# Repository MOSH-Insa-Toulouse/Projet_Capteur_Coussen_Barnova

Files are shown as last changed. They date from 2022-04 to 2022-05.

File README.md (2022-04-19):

# Projet_Capteur_Coussen_Barnova
 2021-2022
 Low-tech pencil drawn strain gauge sensor developed in 4th year Engineering Physics course MOSH (Microcontroller Open Source Hardware) at INSA (National Institute of Applied Sciences) Toulouse.

The project is inspired by Scientific Reports article "Pencil Drawn Strain Gauges and Chemiresistors on Paper" written by Cheng-Wei Lin, Zhibo Zhao, Jaemyung Kim & Jiaxing Huang. This article can be found in our repository.

The aim of this project is to fabricate a reliable strain gauge made of pencil drawn paper.

## Idea
Pencil carbon deposited on the paper is made of percolated graphite particles network where electrons move. Mechanism enabling electrons to move from grain to grain is tunnelling through potential barrier. However, tunnelling depends exponentially on the length of the barrier. When a mechanical stress is applied to the gauge, grains of percolated network spread away. Thus, when a tension is applied to gauge electrons move less => resistance increases. When gauge is compressed electrons move more => resistance decreases.

## Hardware implementation
A photo of our sensor can be found in the repository.

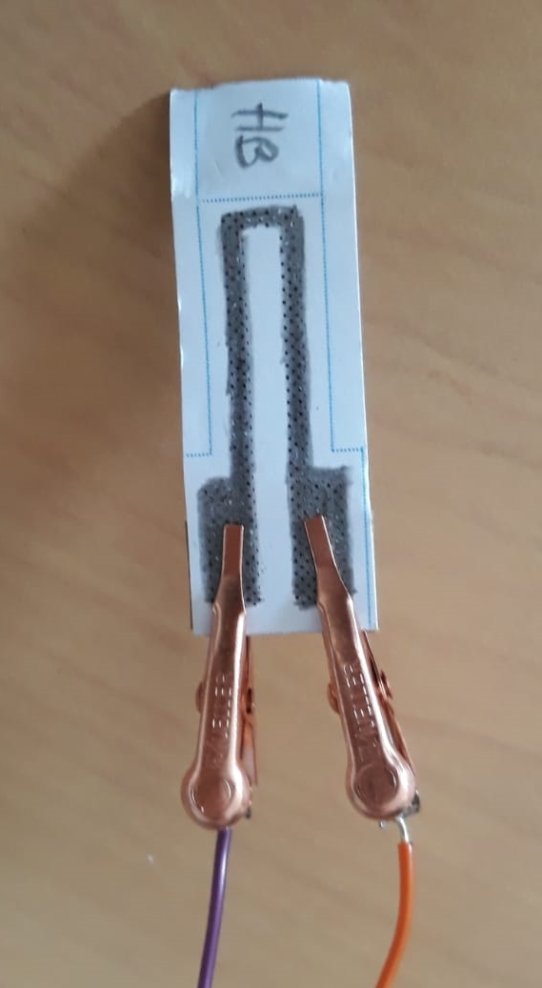
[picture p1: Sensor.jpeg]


Supplying the sensor with 5V induces current in the sensor. However, this current has an order of magnitude of a nanoampere. Ordinary multimeter is not able to detect such a small current. We use LTC1050 amplifier which enables to convert current into a voltage that can be measured thanks to Arduino Uno board.
We dimensioned amplifier circuit in order to filter 50 Hz noise and cut off high frequencies. Further explanations are contained in Electronic_simulation_LTSpice document.
We designed this electrical circuit as a shield PCB (printed circuit board) using KiCad 6.0 software and printed it. KiCad files can be found in KiCad directory.

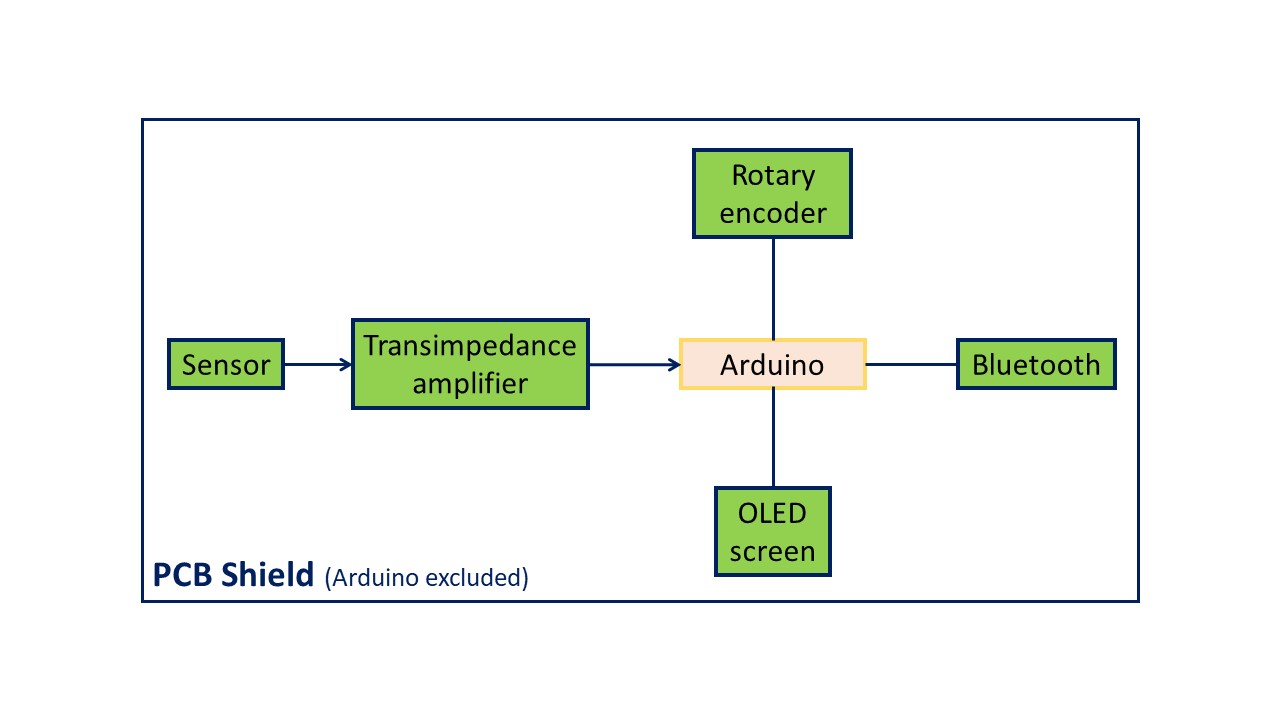
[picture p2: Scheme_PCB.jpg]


## Software implementation
With a focus on customized Arduino board we've written Arduino programs to run OLED screen, rotatory encoder and HC-O5 Bluetooth module enabling to send mesasured data to a smartphone. This code can be found in the directory "code_Arduino". To run the code you will need to download Adafruit_1306 library.
We developed this code without PCB and for the sake of simplicity and efficiency we changed one pin between PCB and code. Switch pin of the rotary encoder is wired to the pin 3 of Arduino instead of pin 5 (as in PCB). The reason is that we use Interrupts in the code and they can be generated only by the Arduino pins 2 and 3.  
Finally, we designed a simple app on MIT App Inventor that receives and plots the data. It can be found in the directory "App". Our app fails when it receives inf value and we did not eliminate this bug. 

## Tests and results

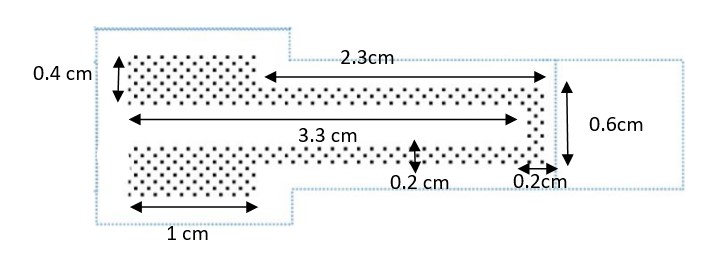
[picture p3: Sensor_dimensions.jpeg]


Our sensor can be drawn with different pencils. Their content is a mixture of clay and carbon. Pencils containing more clay are indicated with H meaning "high". Their stroke is light. Pencils containing more carbon are indicated with B meaning "low" and they draw bolder lines. Here is scale of pencils hardness.



Results can be found in the file Measures. We get linear slope of the calibration curve which confirms that resistance depends on strain. It is possible to make a sensor with pencil drawn paper. We note that sensibility of our sensor is the slope of the linear function - for HB it is 14 385 Mohms/m.
Even though, our sensor gives limited results, we measured how the resistance changes as a function of curvature and we are able to link it to bending. This explanation can be found in the document "Test bench". However, wires connection induced on paper a lot of error because of lack of stability.

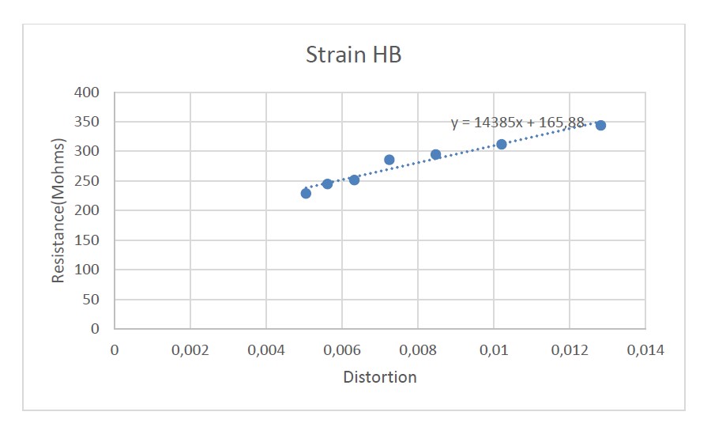
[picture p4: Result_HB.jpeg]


## Limits 
Firstly, PCB oxydized which lead to its malfunction. Most probably, certain pins were connected with the pins they were not supposed to which hindered correct supply and transit.
Furthermore, resistance depends clearly on amount of carbon deposited. This factor is quite difficult to evaluate and to control in our conditions.
Moreover, our measures are not repeatable because paper distorts when we measure relatively big strain. 
Finally, wire connections slip on the paper which alters the resistance. We would need a more reliable connection to decrease average error and get more repeatable results. We could possibly imagine a solution to stabilize the position of the wires connections relatively to each other. 

## Authors
Sarah Barnová : barnova@insa-toulouse.fr
Louise Coussen : coussen@insa-toulouse.fr

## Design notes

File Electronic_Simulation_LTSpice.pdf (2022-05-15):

## Partie électronique analogique - Simulation électrique sous LTSpice

### Sarah Barnova – Louise Coussen

Afin de mesurer la résistance d’un capteur de graphite, on utilise un amplificateur de transimpédance. En effet, on dépose du graphite en frottant un crayon à papier contre un morceau de papier qui fera office de résistance à mesurer. En alimentant le circuit en tension à 5V, on peut considérer ce générateur de tension en série avec notre résistance, que l’on nommera Rsensor. On modélise alors cette configuration par un générateur de courant que l’on nomme Isens. Ainsi, on impose I grâce à une tension d’alimentation fixe et la résistance inconnue Rsensor, et on cherche à mesurer VADC pour déduire cette valeur inconnue. On utilise donc un amplificateur de transimpédance, qui convertit courant en tension.

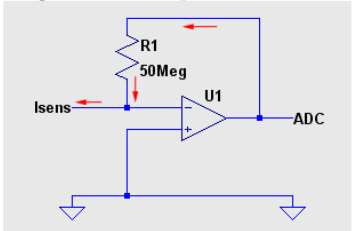
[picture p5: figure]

Le schéma ci-dessus présente la solution la plus minimaliste possible, toutefois, il présente quelques défauts : en effet, le capteur doit être alimenté par une tension négative, et R1 doit être très importante. Toutefois, afin de garantir le bon fonctionnement de ce montage, il est nécessaire d’y implémenter 3 filtres dont nous allons étudier successivement le rôle. Voici donc un amplificateur de transimpédance à 2 étages :

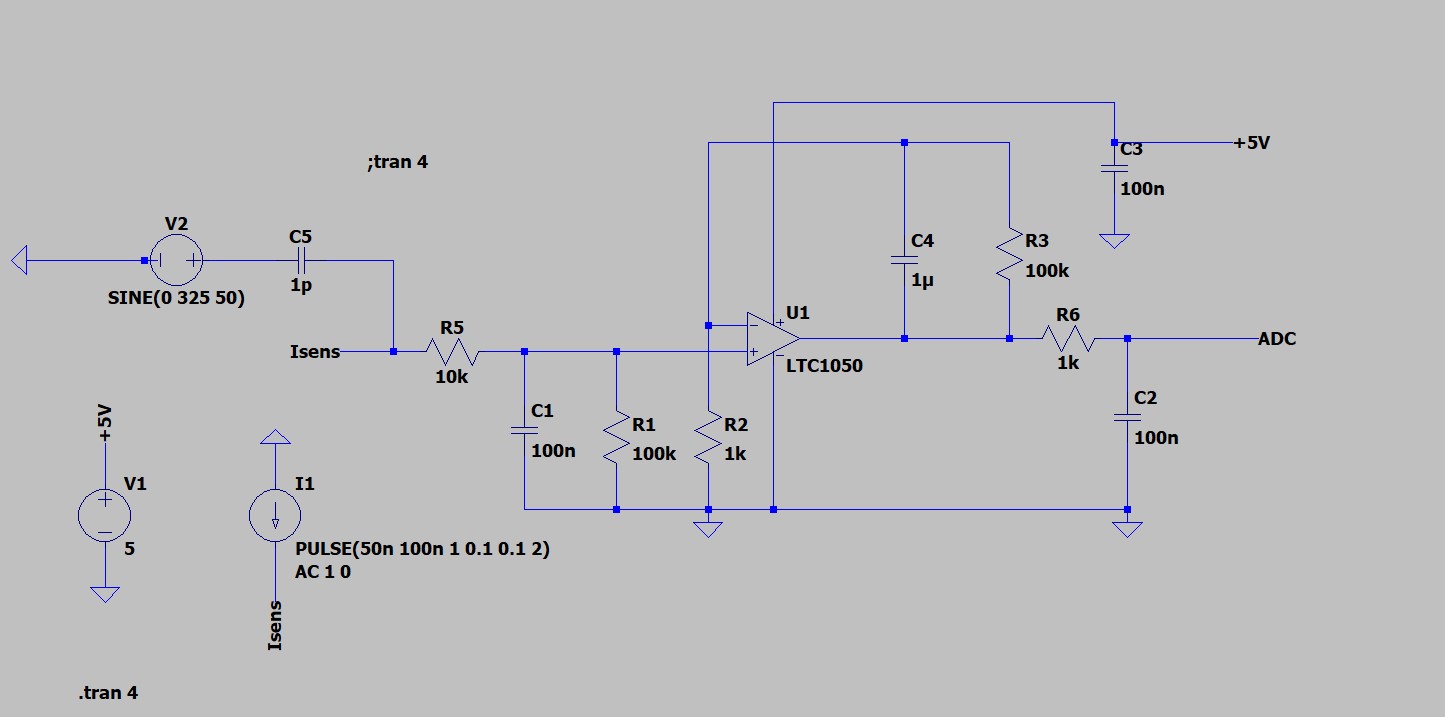
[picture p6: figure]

## Filtre 1 : R1 – C1, filtre passe-bas contre le bruit en courant

Ce premier filtre passe-bas est un filtre RC permettant d’éviter des oscillations trop élevées sur le signal capteur.

On calcule sa fréquence de coupure théorique : f =

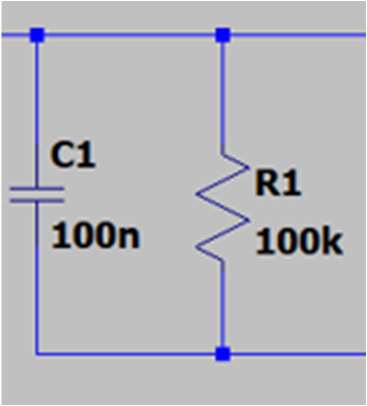
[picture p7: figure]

×.×.

= 15,9 Hz

On simule retrouve cette fréquence de coupure sous LTSpice en désactivant les capacités des autres filtres (on leur confère 0 pour valeur).

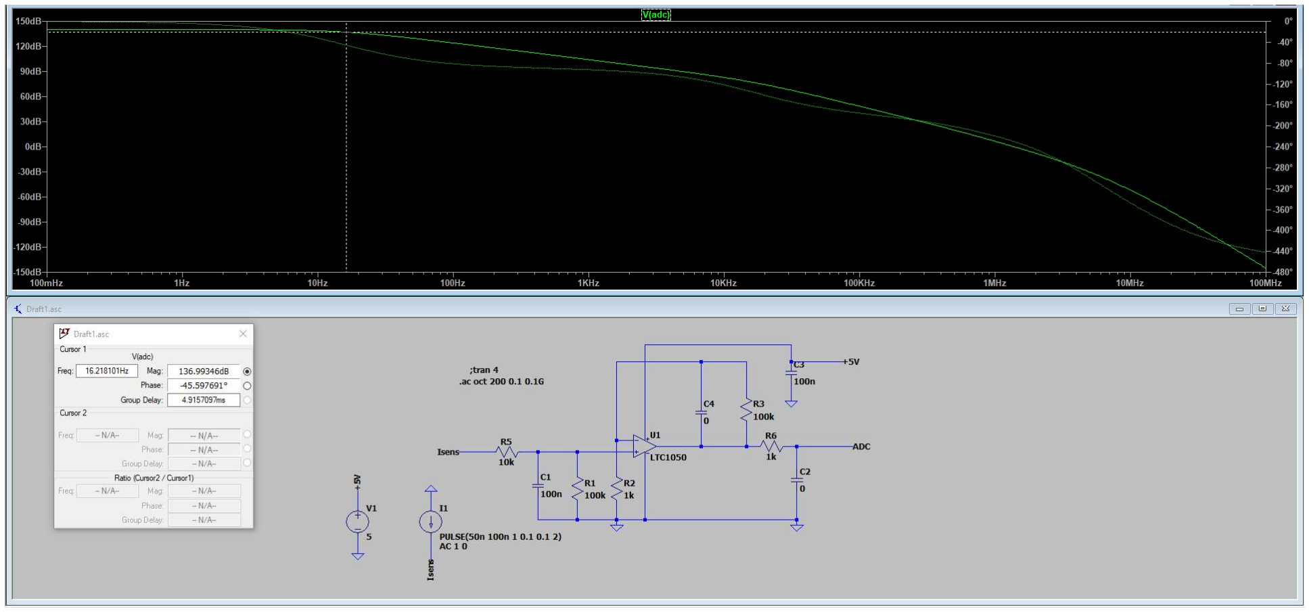
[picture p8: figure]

## Filtre 2 : R3 – C4, filtre actif contre le bruit à 50 Hz

Ce second filtre passe-bas permet de filtrer le bruit à 50 Hz.

On calcule sa fréquence de coupure théorique : f =

×.×.

= 1,59 Hz

On retrouve également cette fréquence de coupure sous LTSpice en désactivant les capacités des autres filtres.

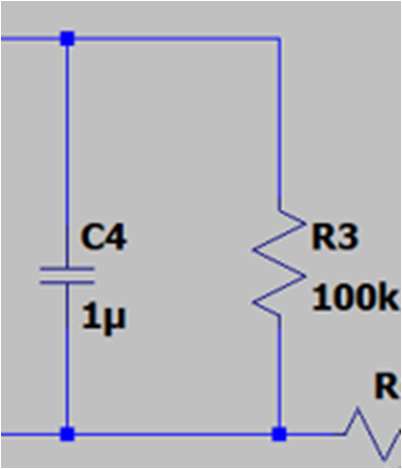
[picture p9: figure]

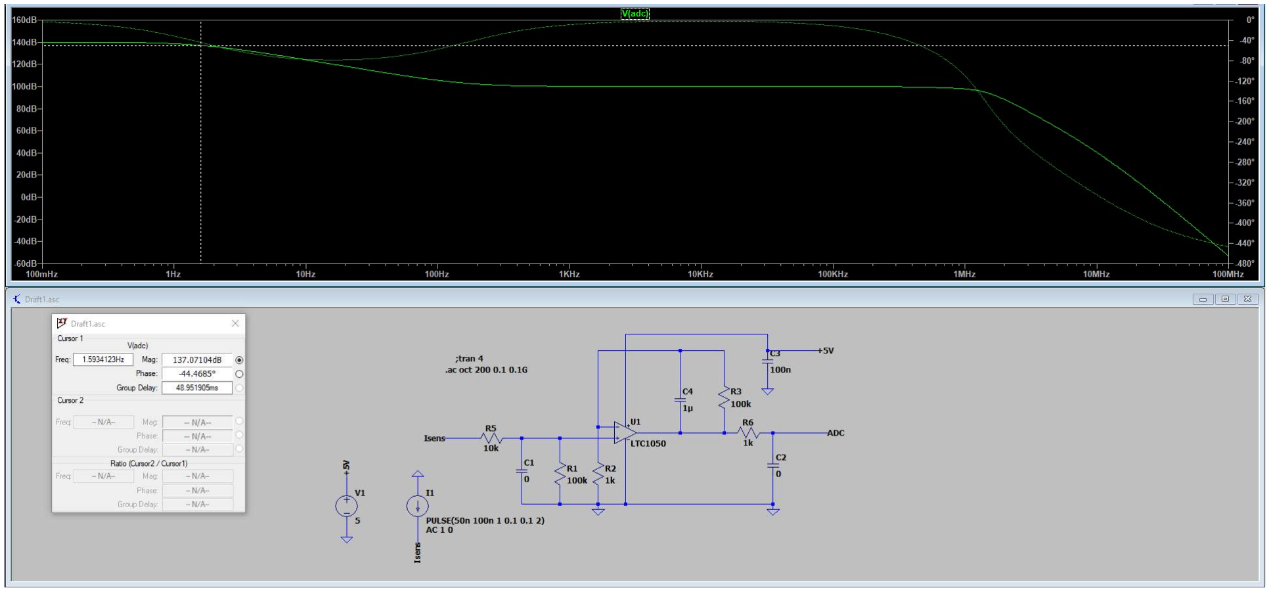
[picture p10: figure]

## Filtre 3 : R6 – C2, filtre de sortie

Ce dernier filtre permet d’éliminer les fréquences trop élevées. En effet, la fréquence d’échantillonnage la plus grande utilisable sans perte de qualité pour l’Arduino Uno est de 15.4 kHz. Le critère de Shannon Nyquist indique que pour qu’un signal puisse être entièrement reconstruit à partir des échantillons prélevés, la fréquence d’échantillonnage doit être strictement supérieure à deux fois la plus grande fréquence présente dans le spectre du signal continu.
Ainsi, on souhaite conserver les fréquences du signal inférieures à 7,5 kHz.
On calcule la fréquence de coupure de ce dernier filtre, puis on la retrouve par simulation sous LTSpice :

f =

×.×. = 1,59 kHz

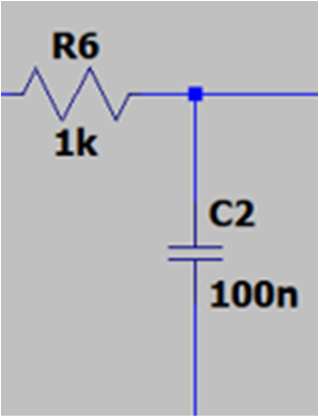
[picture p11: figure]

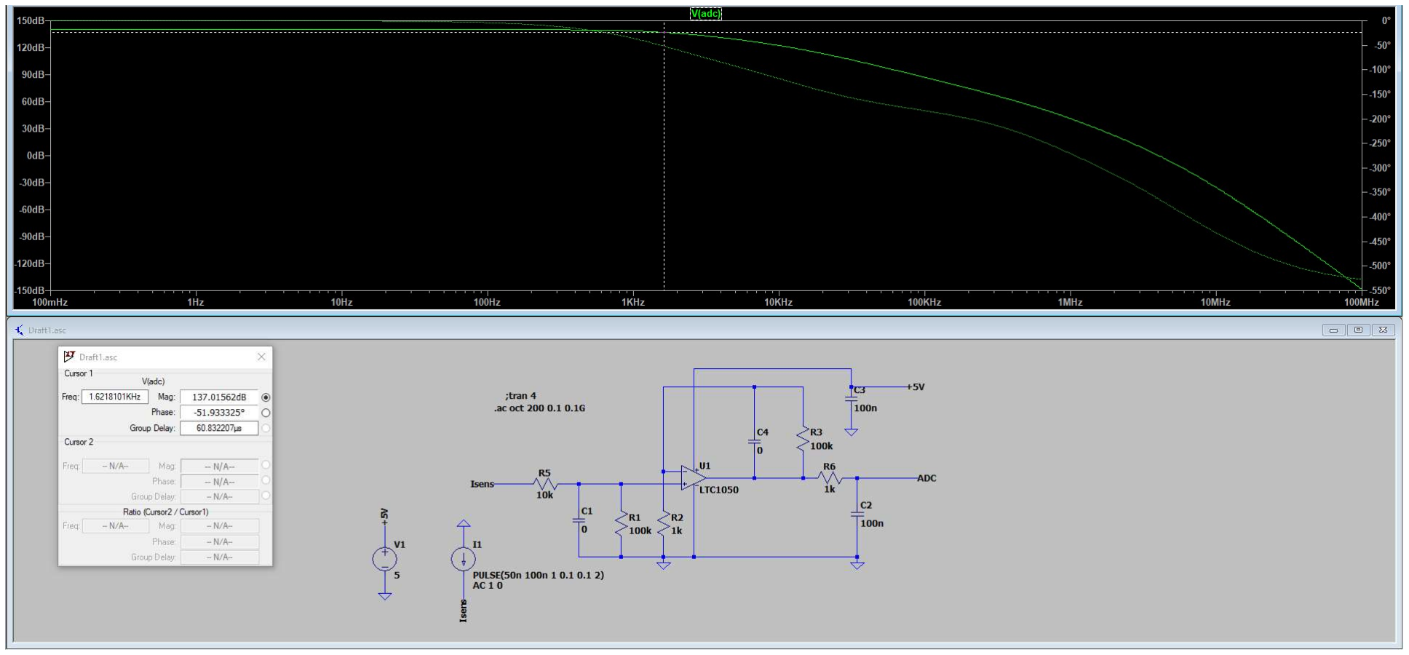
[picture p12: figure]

## Influence du bruit à 50Hz

Voici la transformée de Fourier du signal en sortie (VADC) en AC.

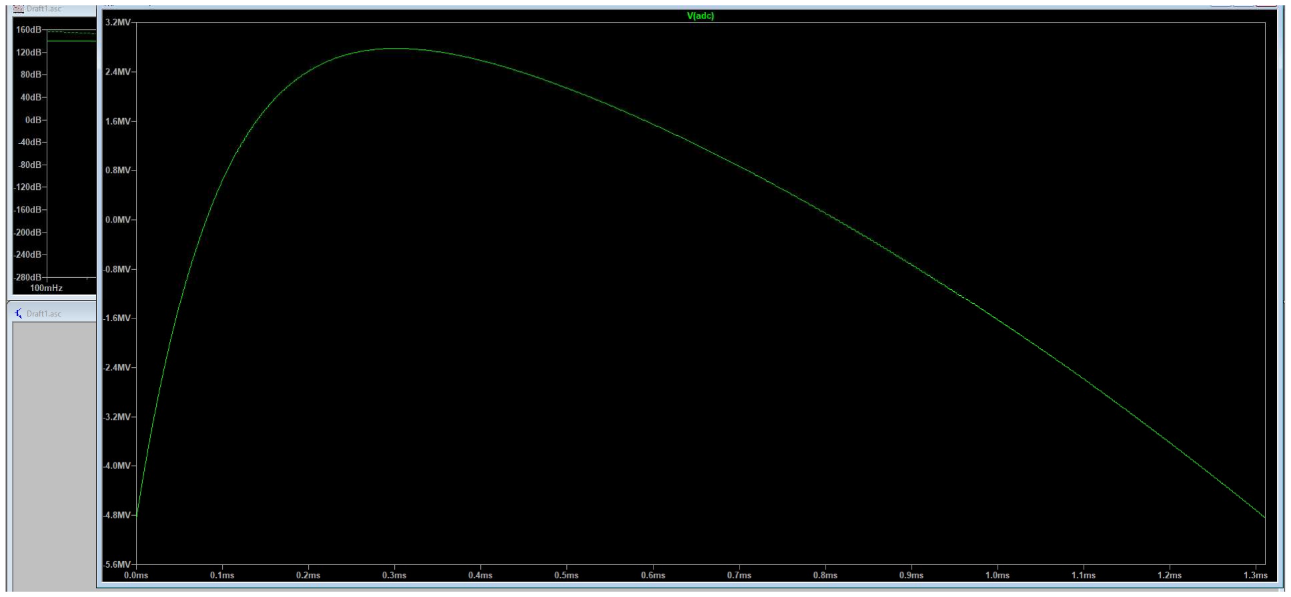
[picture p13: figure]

Voici la transformée de Fourier du signal de sortie (VADC) en transitoire.

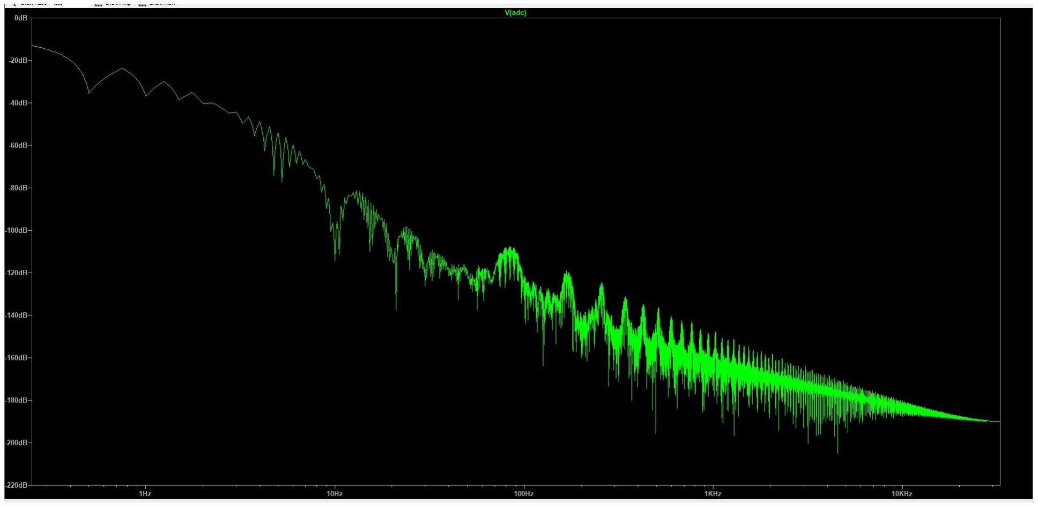
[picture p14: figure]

Ici, on ajoute en parallèle du générateur de courant un générateur de tension sinusoïdal de fréquence 50Hz, en série avec une capacité de couplage CR (1pF) afin de simuler du bruit à 50Hz qui viendrait parasiter le signal. Ci-dessous, en haut à gauche de l’image, on observe un pic sur la transformée de Fourier qui correspond au bruit de 50Hz. On observe juste à droite que le signal est en effet fortement bruité. Pour constater l’effet de la capacité C4 du filtre de bruit, on lui confère tout d’abord une faible valeur (0.1µF).

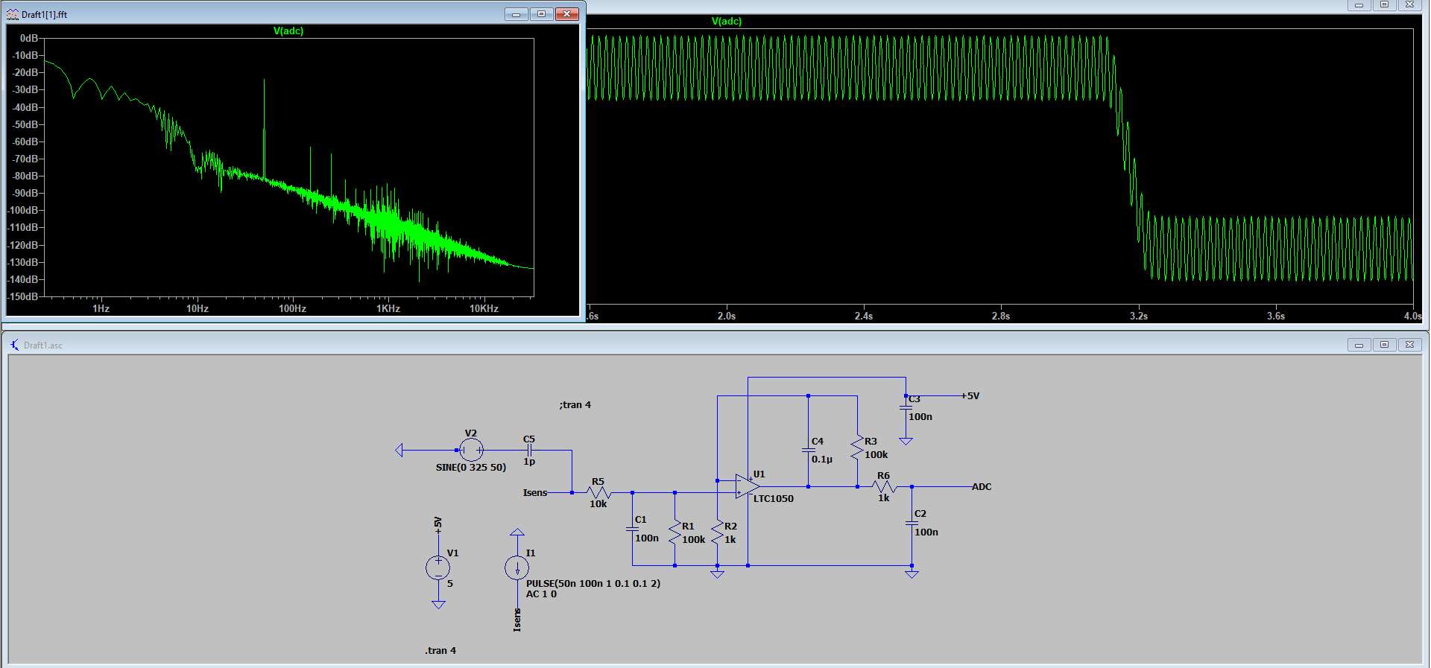
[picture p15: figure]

Puis, ci-dessous, on observe l’influence de ce même bruit pour une valeur de la capacité C4 plus élevée : 1 µF. On constate que le pic de la FFT est plus faible et que le signal est bien moins parasité par le bruit à 50 Hz. On constate bien l’effet de la capacité C4 du filtre de bruit.

## Atténuation globale du bruit en courant à 50 Hz à la fréquence limite de repliement

A 50 Hz, on a une atténuation de 140 dB – 100 dB = 40 dB. A fréquence de Nyquist (f=7,5kHz), aussi appelée fréquence limite de repliement, cette atténuation est de 140 dB – 33 dB ≈ 100 dB.

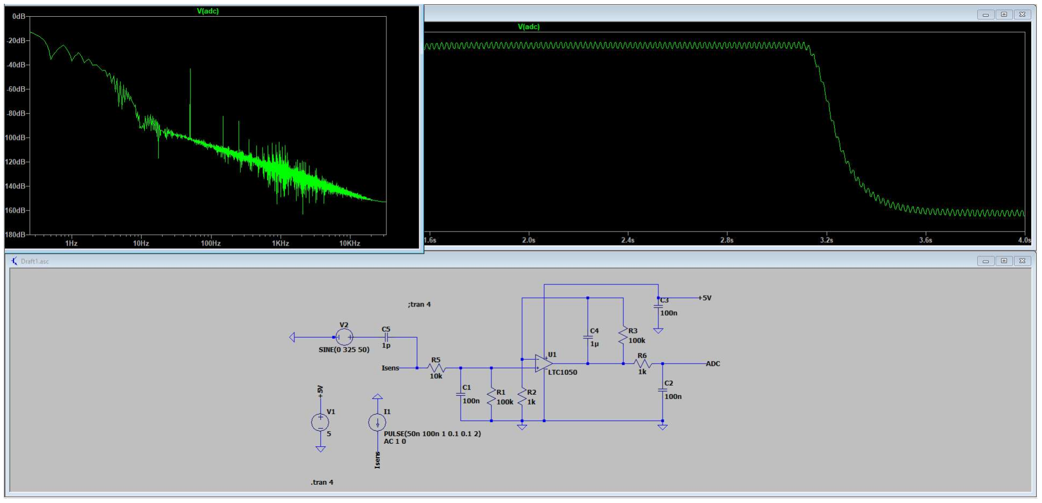
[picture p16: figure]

Pour conclure, par ce choix de circuit électronique :
- En entrée, R5 en entrée protège l’amplificateur opérationnel des décharges électrostatiques
- C1 et R1 forment un filtre passe-bas permettant de limiter le bruit en courant (en entrée)
- R2 est une résistance que l’on pourra changer afin d’adapter le signal en entrée de l’amplificateur et donc en sortie, afin d’obtenir le calibre et la plage de fonctionnement idéale pour le circuit. On a la possibilité de la remplacer plus tard par un potentiomètre digital, qui nous permettra de modifier cette valeur de résistance en fonction de la résistance du capteur obtenue pour différents types de crayon à papier
- C4 et R3 forment un filtre actif permettant de réduire fortement le bruit à 50 Hz
- C2 et R6 forment un filtre de sortie, permettant de respecter le critère de Shannon-Nyquist, et donc la fréquence d’échantillonnage maximale de la carte Arduino

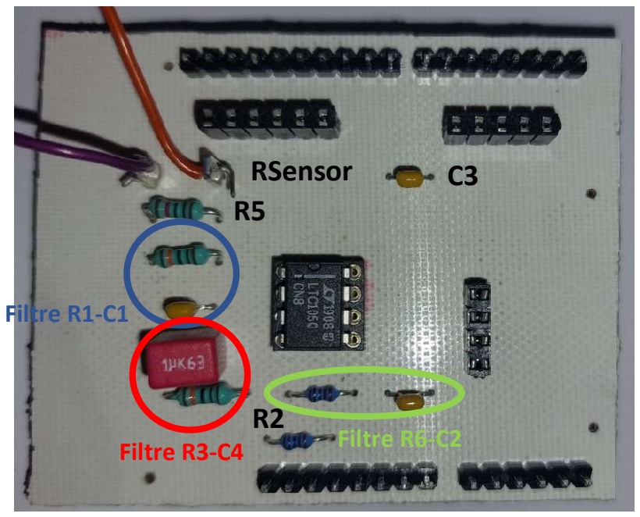
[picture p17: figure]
Filtre R1-C1; Filtre R3-C4; Filtre R6-C2; RSensor

Finalement, après calcul on trouve la formule suivante pour la résistance du capteur :

R = (1 +

R

R

) × R ×

V

V

− R − R

Avec :

R = 100kΩ

R = 1kΩ = R

R = 100kΩ

R = 10kΩ

R = 1kΩ

V = 5V
Et V la tension mesurée

## Conditions nominales

Le circuit électrique a été conçu de telle façon qu’on obtient en sortie, pour VADC, des valeurs comprises entre 0 et 5 Volts. En effet, cette valeur de 5 Volts ne doit pas être dépassée car la carte Arduino supporte une tension maximale de 5 Volts.
De plus, on constate en cliquant sur les entrées + et – de l’amplificateur opérationnel sous LTSpice que ces courants sont très faibles et identiques.

## Influence de l’offset

L’offset voltage est l’erreur constante aux entrées de l’amplificateur différentiel, due à un état non compensé sur l’étage d’entrée de l’amplificateur. On désire faire en sorte que cet offset soit négligeable devant la tension mesurée sur R, qui sera de 10 mV. D’après la datasheet du LCT1050, l’offset typique de cet amplificateur est de 0,5 µV. Cet offset est 2000 fois inférieur à la tension mesurée en R, on le considère donc acceptable.

## Incidence du courant d’entrée

Le courant d’entrée doit être très faible devant I, car on souhaite que le courant traverse R, et non pas l’entrée (amplificateur opérationnel idéal, i = i -> 0). Afin d’éviter de saturer en sortie de l’amplificateur opérationnel, on propose la solution de remplacer R par un potentiomètre digital qui permettra de rendre cette résistance variable. Ainsi, cela permettra de faire passer le moins de courant possible en entrée de l’amplificateur opérationnel, ce courant devant être plus petit que I, et donc d’éviter la saturation.

Ce document a été rédigé à l’aide du travail et de documents fournis par monsieur Jean-Louis Noullet et de monsieur Jérémie Grisolia.

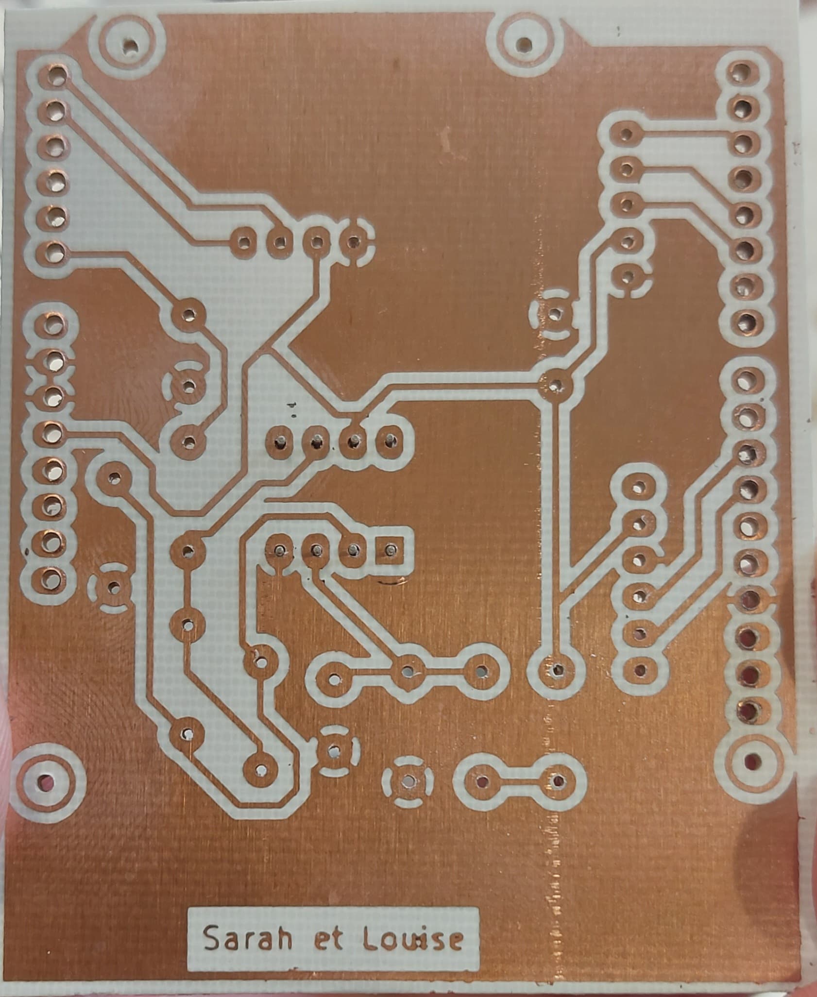
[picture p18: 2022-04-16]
PCB.jpg

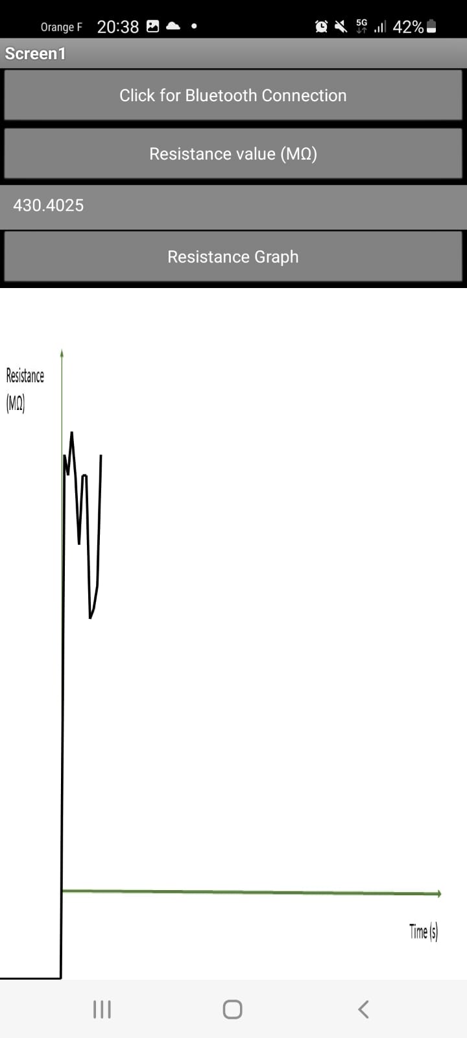
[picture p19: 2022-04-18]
App/Graph_example.jpeg

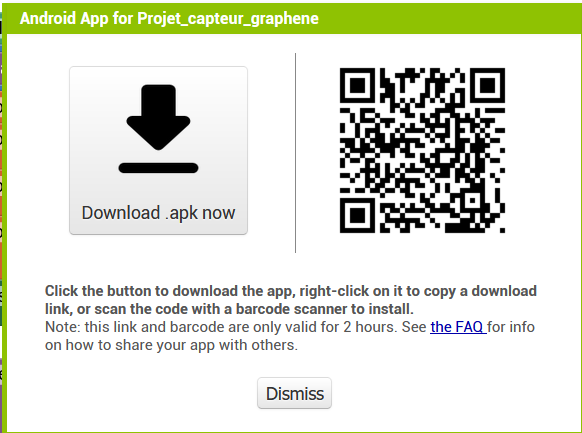
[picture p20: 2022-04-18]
App/Flashcode_Mobile_App_Final.png

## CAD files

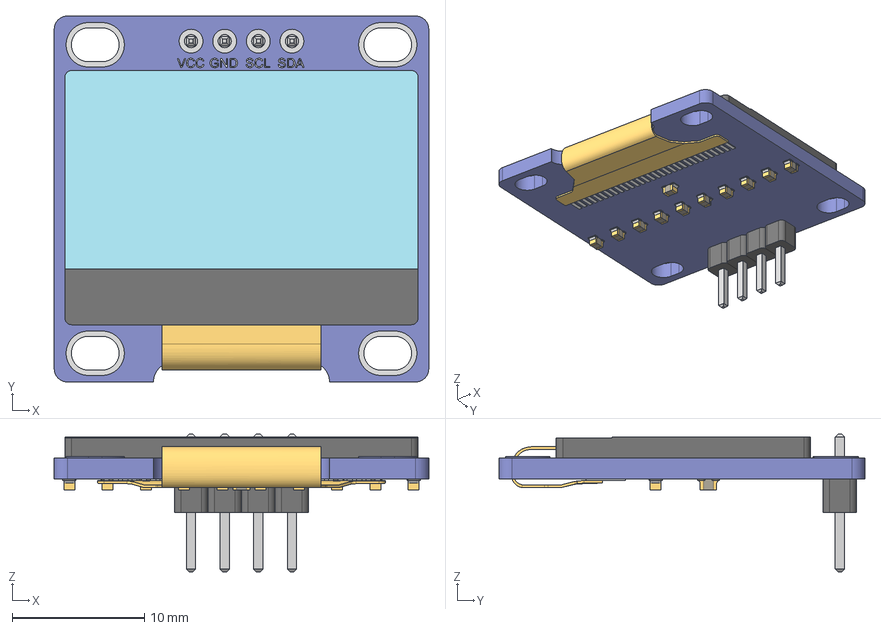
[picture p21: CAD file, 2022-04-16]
KiCad/Tela-OLed-128x64-v15.step
28.3 x 27.6 x 10.4 mm
Pantalla
PADS
PINOS
fLEX
res x 11

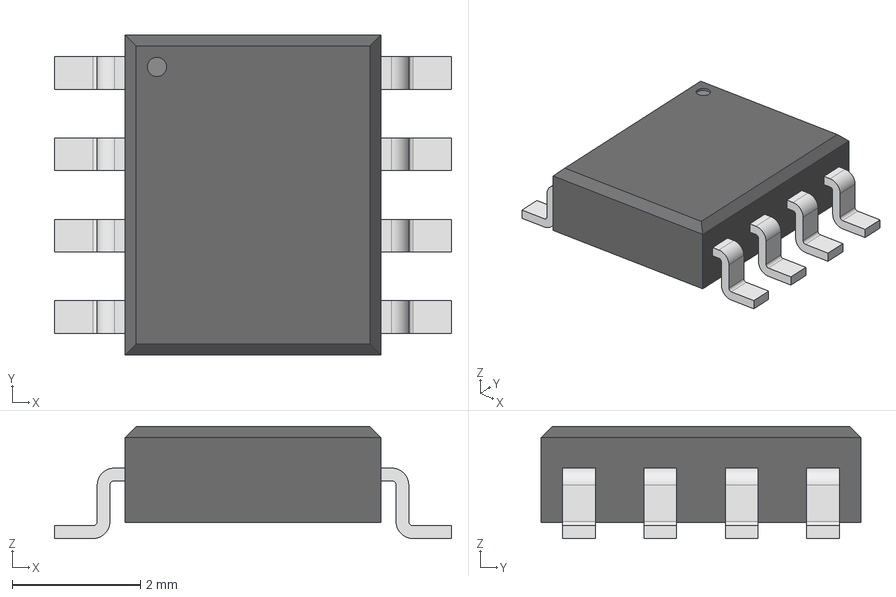
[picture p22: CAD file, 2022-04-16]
KiCad/SOIC127P600X175-8N.step
6.20 x 5.00 x 1.75 mm

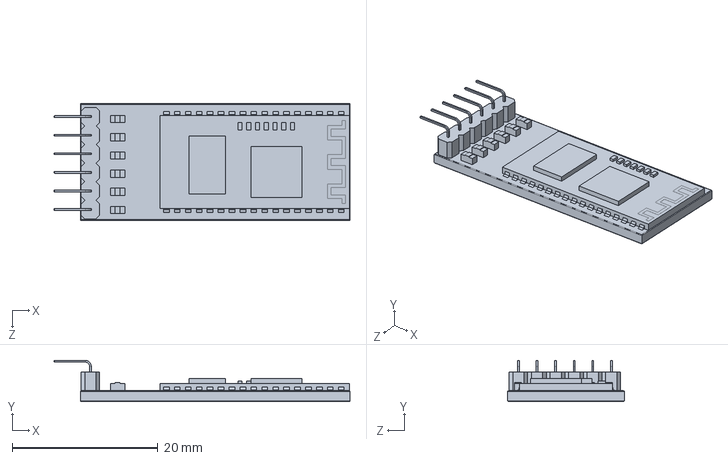
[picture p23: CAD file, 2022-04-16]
KiCad/HC05.step
40.6 x 5.67 x 16.0 mm

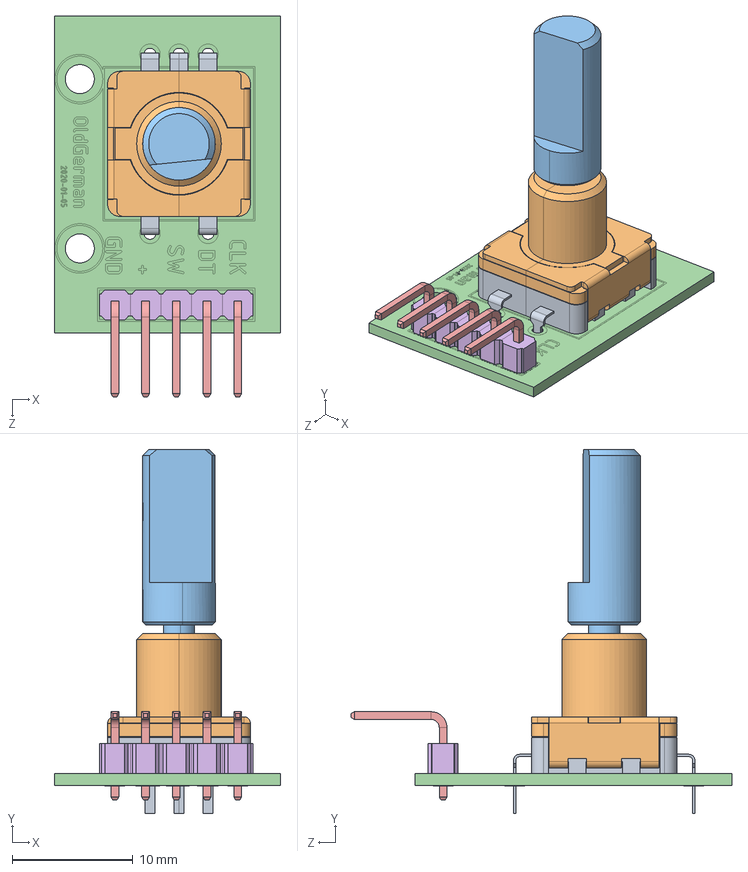
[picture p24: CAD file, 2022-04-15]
KiCad/KY-040 Rotary Encoder.STEP
18.7 x 30.1 x 31.5 mm
Rotary Encoder
D-handle
pcb
2.54 5PIN 90

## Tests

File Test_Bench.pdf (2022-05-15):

## Banc de test et exploitation des mesures

## Jauge de contrainte

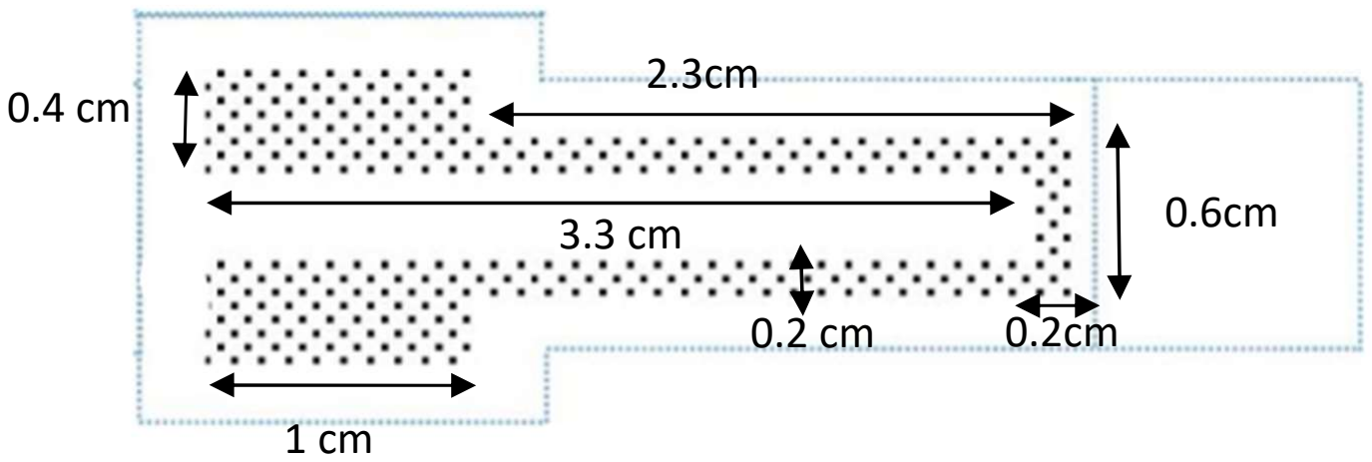
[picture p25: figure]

Les résistances mesurées sont créées à partir de dessins de gabarit imprimés sur du papier suffisamment épais pour résister aux essais de flexion et de compression qui seront effectués. La zone à crayonner est celle en pointillé. Les crayons testés seront HB et B. La dureté des mines est classée comme suit :

Hard | Medium | Light

Avec : H = Dur (ou sec)

B = Gras (ou huileux)

HB = Hard Bold (ou moyen)

F = Pointe fine (milieu de l'échelle)

Les mines sont composées d'argile et de graphite. Une mine tendre, qui se trouve du côté B, contient plus de graphite et moins d'argile qu'une mine dure, du côté H, qui contiendra moins de graphite et plus d'argile.

Le fait de dessiner sur du papier crée une fine couche de graphite percolée, qui est un système granulaire. En fléchissant le papier recouvert de crayon, dans un sens puis dans l’autre, le réseau de graphite se resserre ou se relâche, respectivement. Ainsi, en compression, les électrons se déplacent plus facilement et la résistance diminue. Au contraire, en traction, les électrons ont moins de chemins possibles pour traverser la couche de graphite du papier et la résistance augmente.

## Banc de test

Le banc d'essai utilisé est un banc de test en plastique imprimé en 3D. Il est composé de 7 demi-cercles successifs, dont le rayon de courbure est décroissant. Leurs diamètres respectifs sont les suivants : 4,95, 4,45, 3,95, 3,45, 2,95, 2,45 et 1,95 cm, que nous avons pu mesurer à l’aide d’un pied à coulisse. En partant du demi-cercle le plus grand vers celui qui a le plus petit diamètre, on pose le papier en traction, ou dans l’autre sens, en compression, et on attend que la résistance renvoyée par le programme associé au programme Arduino d’utilisation de notre capteur se stabilise avant de la noter.

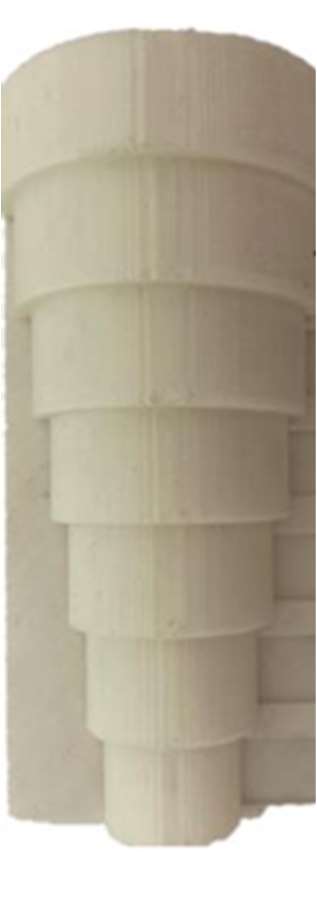
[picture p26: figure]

## Déformation d’une poutre encastrée soumise à une force perpendiculaire sur l’extrémité libre

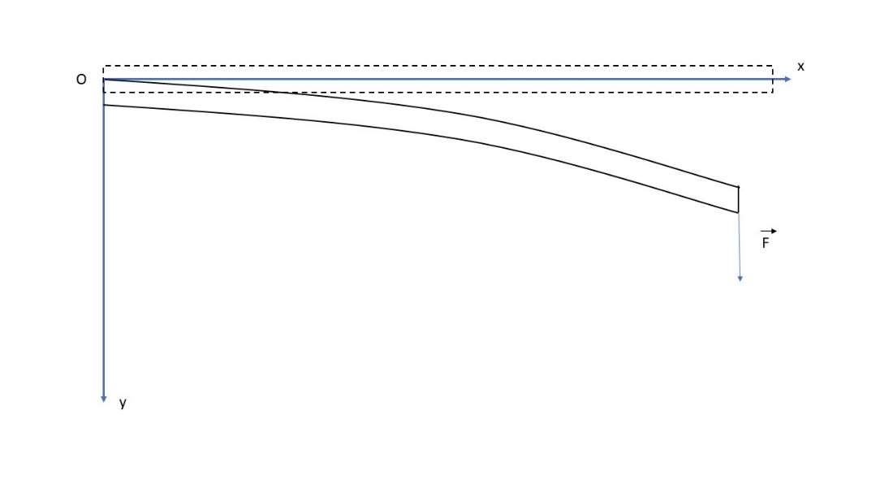
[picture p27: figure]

On considère notre capteur comme une poutre encastrée à une extrémité (celle tenue par les pinces crocodiles) et soumise à une force à l’autre extrémité. On la considère de section rectangulaire :

- De longueur L le long de l’axe Ox
- D’épaisseur e le long de l’axe Oy
- Et enfin de largeur w le long de l’axe Oz

Avec e et w << L. La poutre est encastrée en x=0. Ox est parallèle à la direction d’encastrement. A l’extrémité de la poutre, (x=L), on applique une force F⃗ dans la direction y > 0 qui provoque la flexion de la poutre.

Aucune force n’est appliquée dans la direction Ox. On a donc :

σ dy dz = 0

w E

y − y
R

dy = 0

(y − y)

dy = 0
y
2

− yy

= 0

e

2

− ye = 0

y =

e
2
Ainsi, la surface neutre est située le long de la poutre, en son centre.

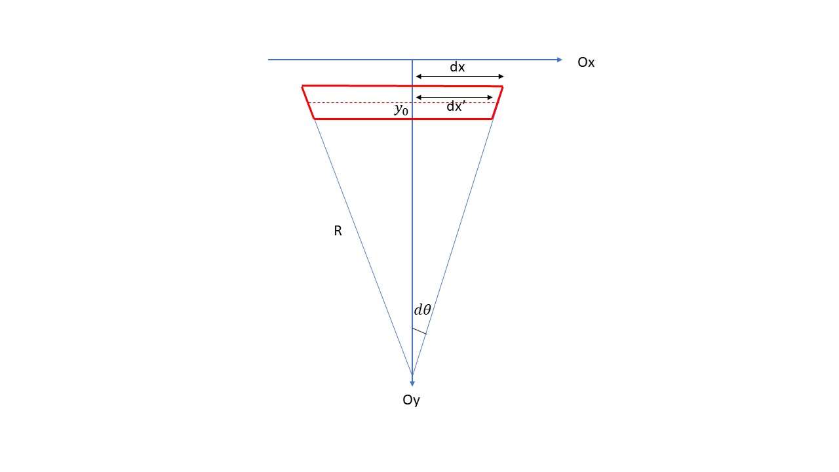
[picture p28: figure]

En rouge, une tranche mince transversale de la poutre en flexion. R est le rayon de courbure de la flexion. On fait les approximations suivantes :

La flexion est faible : R >> L

La flexion est pure : la poutre n’est soumise à aucune tension ou compression supplémentaire.

(w ≠0)

R est la courbure de la surface située en y = y. Ayant e << L, on s’intéresse à y < y, car c’est sur cette face que le graphite est déposé en une couche d’épaisseur quasiment nulle. Si la « poutre » subit une force F⃗ dans la direction y > 0, on a dx’>dx pour y < y, avec dx’ la longueur d’un élément qui avait la longueur dx avant la déformation (la longueur de la poutre, en surface, où nous avons déposé le graphite, s’est étirée).

Le rayon de courbure d’une surface pour laquelle y = cte avant la flexion est R – (y − y). On a :

dx′(y)
R − (y − y)

= dθ

Et dθ faible, donc tan dθ ≈ dθ.

Or, en y = y :

dx′(y)
R

= dθ =

dx
R
D’où :

dx′
R − (y − y)

=

dx
R
L’allongement relatif est donc :

dx′
dx =

R − (y − y)
R
Soit

= 1 −

D’où ε(y) =

= −

Or comme démontré plus haut, y =

On se place à la surface haute de la poutre, c’est-à-dire à l’origine du repère sur le schéma plus haut, et y = 0. On en déduit :

ε(0) =

y
R

=

e
2R
Avec, pour rappel, e l’épaisseur de la jauge et R le rayon de courbure du demi-cercle du banc de test utilisé.

## Exploitation des mesures

Résistance sans déformation : 30 MOhms

### 2B en compression

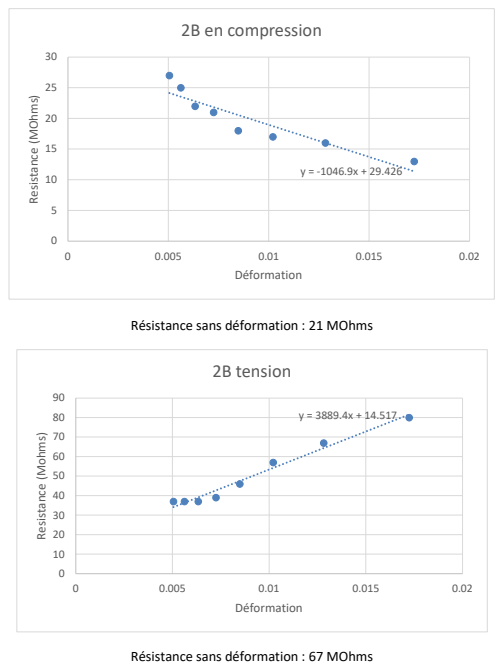
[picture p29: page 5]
0.02 Resistance ⁽MOhms⁾; Déformation; 0.02 Resistance ⁽Mohms⁾; 2B tension

Résistance sans déformation : 21 MOhms

Résistance sans déformation : 67 MOhms

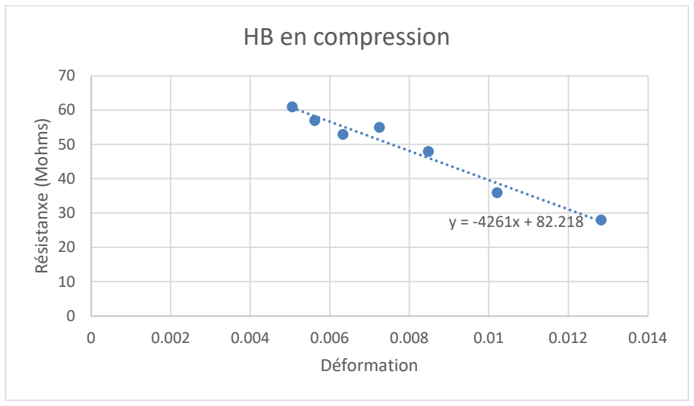
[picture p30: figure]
0.014 Résistanxe ⁽Mohms⁾; Déformation; HB en compression

Résistance sans déformation : 178 MOhms

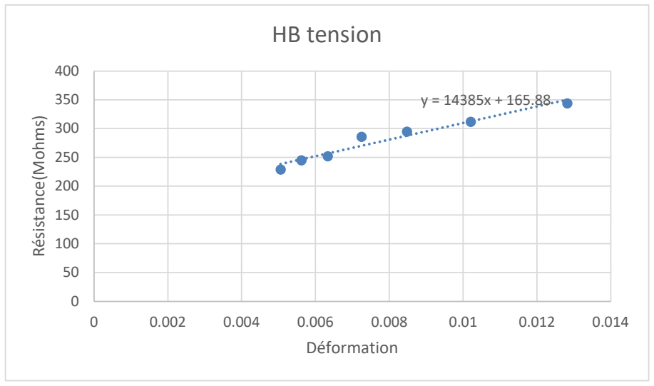
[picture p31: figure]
0.014 Résistance⁽Mohms⁾; Déformation; HB tension

Remarque : Grâce à la courbe de tendance affine que l'on a pour ces courbes, on retrouve bien la valeur de résistance typique (sans déformation) en tant qu'ordonnée à l'origine, c'est-à-dire epsilon =0. De plus, on constate que la sensibilité (c’est-à-dire la pente des courbes de tendance), est meilleure pour les crayons HB que pour les crayons 2B, comme indiqué dans les travaux sur lesquels nous nous sommes basées pour ce projet. Plus le crayon est dur, moins il y a de jonctions tunnel, et plus elles subissent la déformation.

## Limites du capteur

Toutefois, ce capteur présente des limites. En effet, la résistance mesurée dépend fortement de la quantité de crayon appliquée. De plus, le papier subit une déformation progressive, certainement plastique puisque le papier ne revient jamais dans son état initial. Puis, les pinces crocodiles empêchent un mouvement libre de la poutre et arrachent du crayon là où elles sont positionnées. Ensuite, les calculs ci-dessus sont issus de nombreuses hypothèses et approximations, qui peuvent éloigner le résultat de la réalité physique. Enfin, l’erreur est humaine, et les résultats peuvent dépendre de la façon dont ont été positionné les pinces crocodiles et dont la jauge a été déformée.

Ce document a été rédigé à l’aide du cours sur les flexions faibles des poutres de l’université de Diderot de Paris.

https://www.google.com/url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

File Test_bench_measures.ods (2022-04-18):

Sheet: Final_results_HB,_2B
HB | Tension |  | Compression |  | Compression | Tension
Sans déformation | 178 |  | 67 |  | deltaR/R0 | deltaR/R0
4.95 | 229 | 0.005050505 | 61 | -0.005050505 | 60 | 228
4.45 | 245 | 0.005617978 | 57 | -0.005617978 | 56 | 244
3.95 | 252 | 0.006329114 | 53 | -0.006329114 | 52 | 251
3.45 | 286 | 0.007246377 | 55 | -0.007246377 | 54 | 285
2.95 | 295 | 0.008474576 | 48 | -0.008474576 | 47 | 294
2.45 | 312 | 0.010204082 | 36 | -0.010204082 | 35 | 311
1.95 | 344 | 0.012820513 | 28 | -0.012820513 | 27 | 343
2B | Tension |  | Compression
Sans déformation | 21 |  | 30
4.95 | 37 | 0.005050505 | 27 | -0.005050505
4.45 | 37 | 0.005617978 | 25 | -0.005617978
3.95 | 37 | 0.006329114 | 22 | -0.006329114
3.45 | 39 | 0.007246377 | 21 | -0.007246377
2.95 | 46 | 0.008474576 | 18 | -0.008474576
2.45 | 57 | 0.010204082 | 17 | -0.010204082
1.95 | 67 | 0.012820513 | 16 | -0.012820513
1.45 | 80 | 0.017241379 | 13 | -0.017241379
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

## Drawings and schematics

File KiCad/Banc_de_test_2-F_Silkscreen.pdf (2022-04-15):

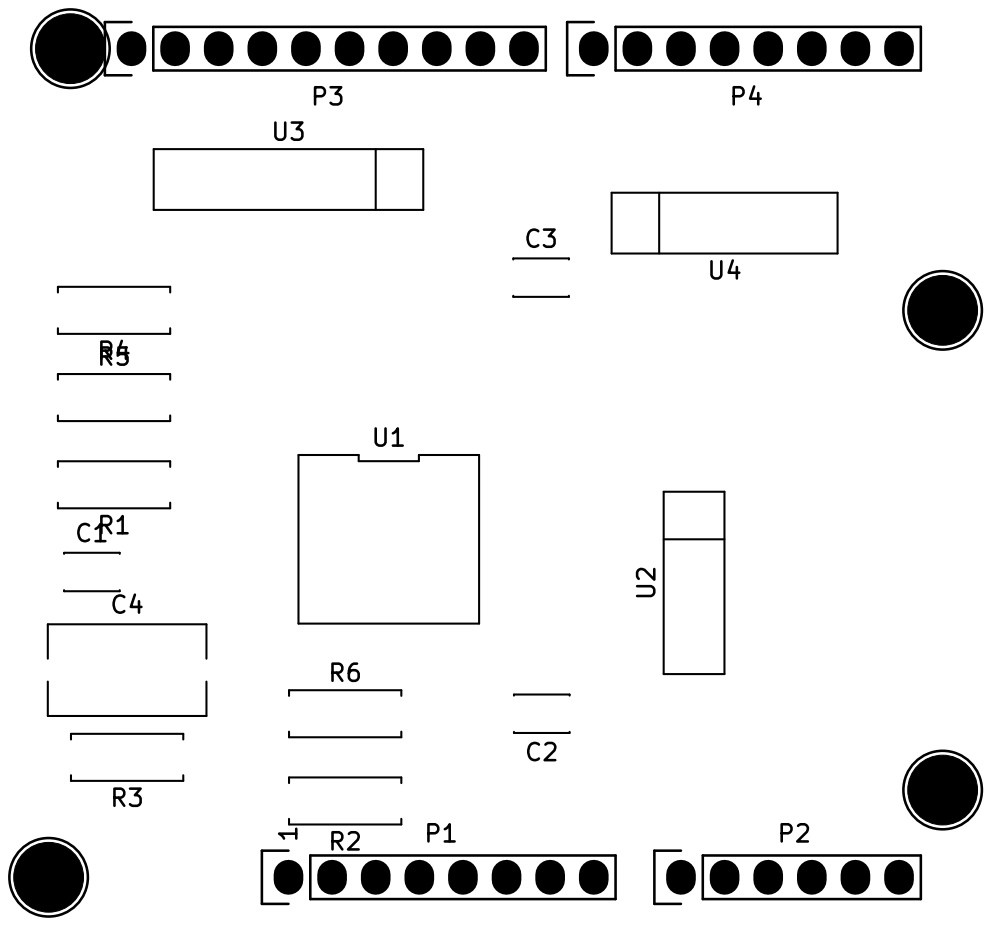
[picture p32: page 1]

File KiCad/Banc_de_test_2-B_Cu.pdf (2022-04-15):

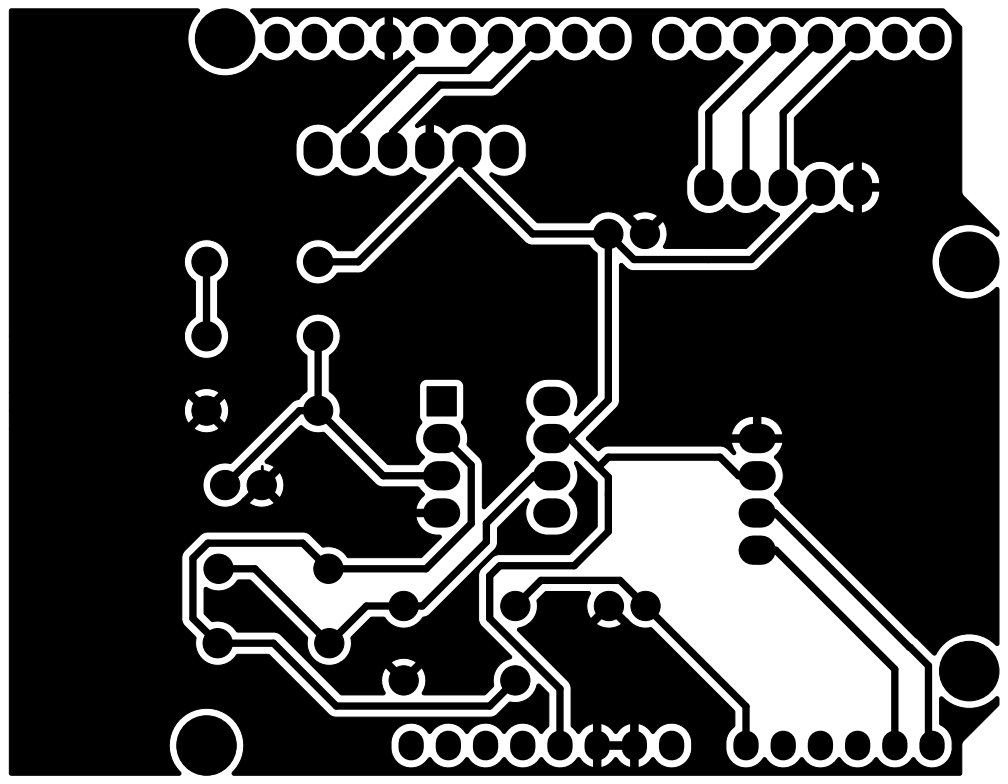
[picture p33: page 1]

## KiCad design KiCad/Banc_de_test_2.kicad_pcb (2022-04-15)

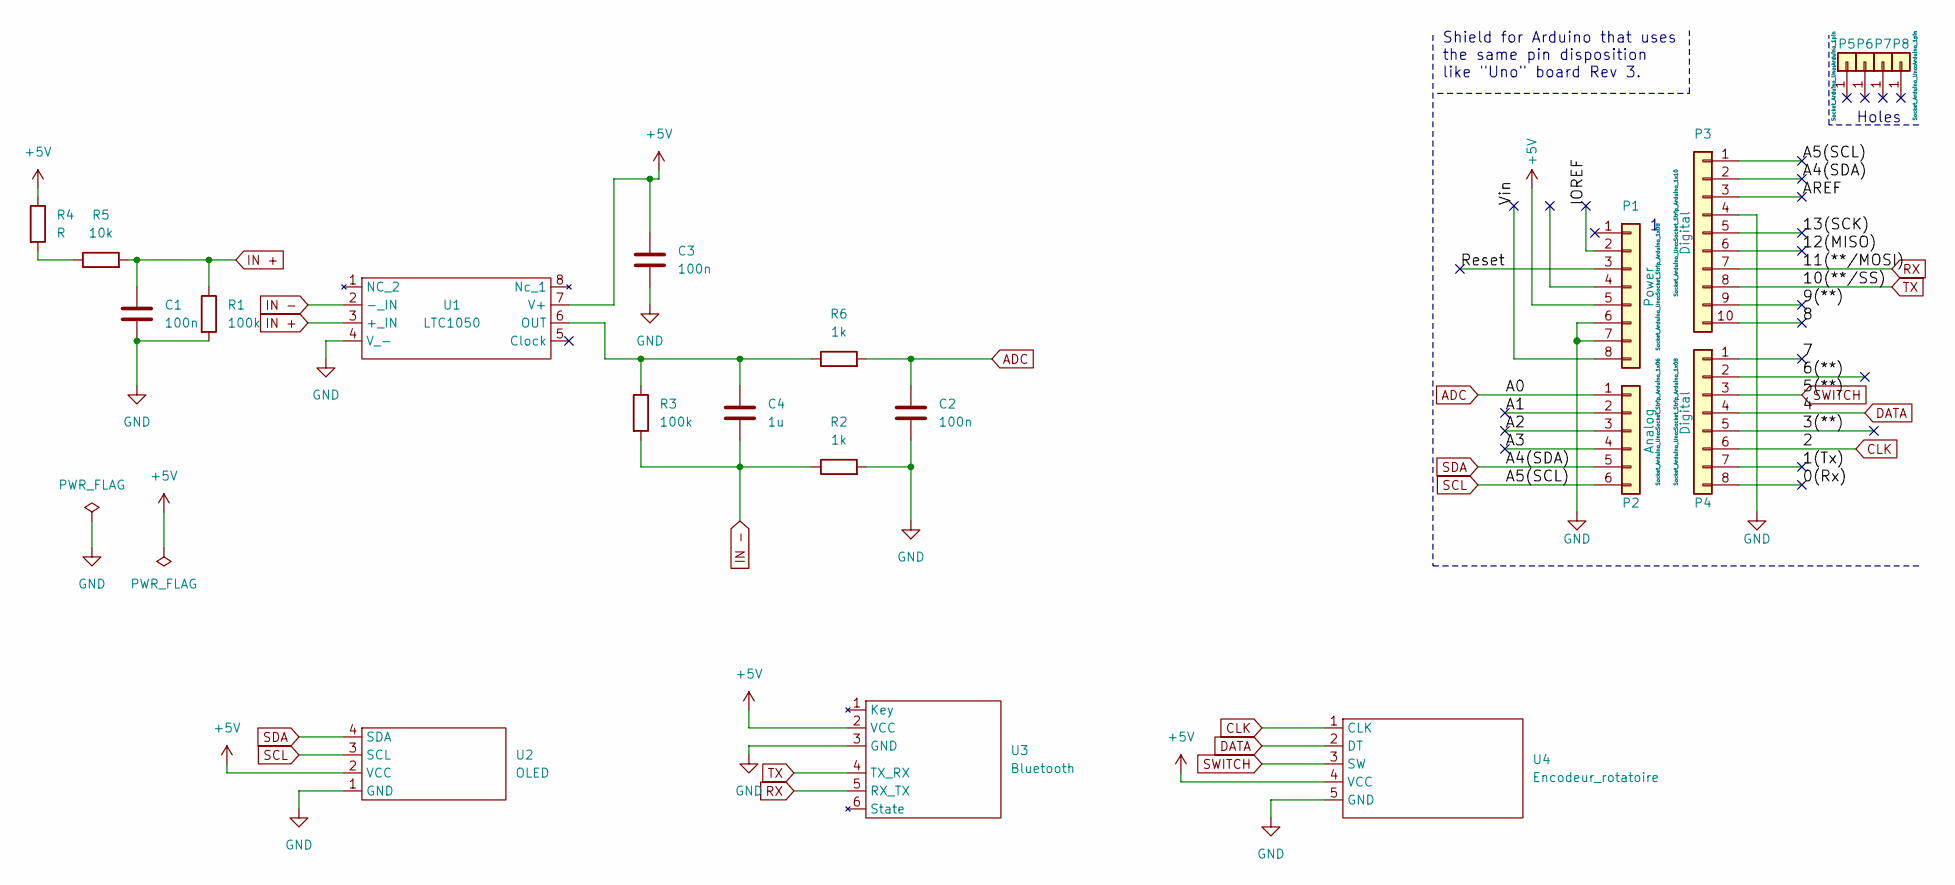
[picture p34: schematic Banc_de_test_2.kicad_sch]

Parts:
C1, C2, C3: 100n; C_Disc_D5.0mm_W2.5mm_P5.00mm
C4: 1u; C_Rect_L9.0mm_W5.1mm_P7.50mm_MKT
P1: Power; Socket_Strip_Arduino_1x08
P2: Analog; Socket_Strip_Arduino_1x06
P3: Digital; Socket_Strip_Arduino_1x10
P4: Digital; Socket_Strip_Arduino_1x08
P5, P6, P7, P8: CONN_01X01; Arduino_1pin
R1, R3: 100k; R_Axial_DIN0207_L6.3mm_D2.5mm_P7.62mm_Horizontal
R2, R6: 1k; R_Axial_DIN0207_L6.3mm_D2.5mm_P7.62mm_Horizontal
R4: R; R_Axial_DIN0207_L6.3mm_D2.5mm_P7.62mm_Horizontal
R5: 10k; R_Axial_DIN0207_L6.3mm_D2.5mm_P7.62mm_Horizontal
U1: LTC1050
U2: OLED
U3: Bluetooth
U4: Encodeur_rotatoire; Encodeur_rot

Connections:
+5V: C3.1, P1.5, R4.1, U1.7 (V+), U2.2 (VCC), U3.2 (VCC), U4.4 (VCC)
/0(Rx): P4.8
/1(Tx): P4.7
/3(**): P4.5
/6(**): P4.2
/7: P4.1
/8: P3.10
/9(**): P3.9
/12(MISO): P3.6
/13(SCK): P3.5
/A1: P2.2
/A2: P2.3
/A3: P2.4
/AREF: P3.3
/IOREF: P1.2
/Reset: P1.3
/Vin: P1.8
ADC: C2.1, P2.1, R6.2
CLK: P4.6, U4.1 (CLK)
DATA: P4.4, U4.2 (DT)
GND: C1.2, C2.2, C3.2, P1.6, P1.7, P3.4, R1.2, R2.2, U1.4 (V_-), U2.1 (GND), U3.3 (GND), U4.5 (GND)
IN +: C1.1, R1.1, R5.2, U1.3 (+_IN)
IN -: C4.2, R2.1, R3.2, U1.2 (-_IN)
unnamed: C4.1, R3.1, R6.1, U1.6 (OUT)
unnamed: R4.2, R5.1
RX: P3.7, U3.5 (RX_TX)
SCL: P2.6, P3.1, U2.3 (SCL)
SDA: P2.5, P3.2, U2.4 (SDA)
SWITCH: P4.3, U4.3 (SW)
TX: P3.8, U3.4 (TX_RX)

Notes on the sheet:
Holes
Shield for Arduino that uses the same pin disposition like "Uno" board Rev 3.

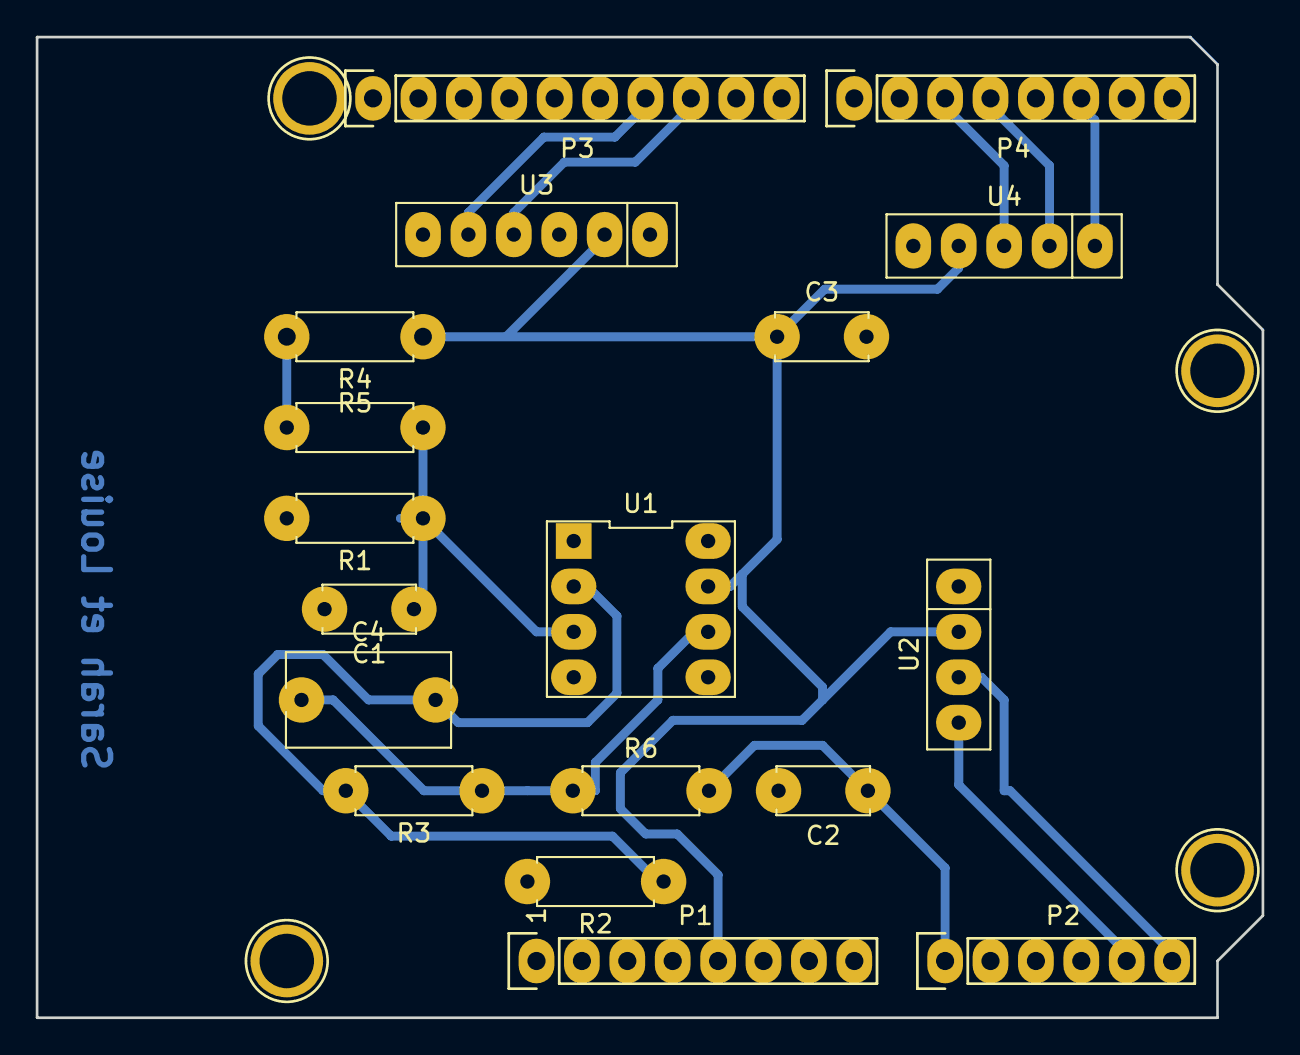
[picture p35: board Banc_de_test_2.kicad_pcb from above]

Board: 2 copper layers, 68.6 x 54.9 mm, 22 parts (0 on the bottom side), 14 nets.

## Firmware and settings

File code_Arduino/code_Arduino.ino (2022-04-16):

// Bluetooth _____________
#include <SoftwareSerial.h>
#define rxPin 10
#define txPin 11
#define baudrate 9600
SoftwareSerial mySerial(rxPin,txPin);

const int Vadc=A0;

// _________ OLED __________________
#include <Adafruit_SSD1306.h>
#define nombreDePixelsEnLargeur 128
#define nombreDePixelsEnHauteur 64
#define brocheResetOLED -1
#define adresseI2CecranOLED 0x3C

Adafruit_SSD1306 ecranOLED (nombreDePixelsEnLargeur, nombreDePixelsEnHauteur, &Wire, brocheResetOLED);

// _________ Encodeur rotatoire ___________
#define encoder0PinA 2
#define encoder0PinB 4
#define Switch 3
volatile unsigned int encoder0Pos=0;
volatile unsigned int Encoder_memo=0;
volatile unsigned int switch0=0;
volatile unsigned int Switch_memo=0;
int line = 0;

void setup() {
  // put your setup code here, to run once:
  // _______ Bluetooth _____________
  pinMode(rxPin, INPUT);
  pinMode(txPin, OUTPUT);
  mySerial.begin(baudrate);
  
  Serial.begin(baudrate);
  Serial.print("Demarrage de programme");
  // ________ OLED __________________
  if (!ecranOLED.begin(SSD1306_SWITCHCAPVCC, adresseI2CecranOLED))
    while(1);
  byte tailleDeCaractere=2; 
  ecranOLED.clearDisplay();
  ecranOLED.setTextSize(tailleDeCaractere);
  ecranOLED.setCursor(0,0);
  ecranOLED.setTextColor(SSD1306_WHITE);
  ecranOLED.println("Menu :");
  ecranOLED.println("Resistance");
  ecranOLED.println("Encoder");
  ecranOLED.println("Authors");
  ecranOLED.display();
  // ________ Encodeur rotatoire _____________
  pinMode (encoder0PinA, INPUT);
  digitalWrite(encoder0PinA, HIGH);
  pinMode(encoder0PinB,INPUT);
  digitalWrite(encoder0PinB,HIGH);
  attachInterrupt(0, doEncoder, RISING);
  pinMode(Switch,INPUT);
  digitalWrite(Switch,HIGH);
  attachInterrupt(1, doSwitch, RISING);
}

void loop() {
  Serial.println("");
  // ________ Lecture de la résistance ___________________
  double Voltage=analogRead(Vadc)*5.0/1023.0;
  delay(1800);
  Serial.print(Voltage);
  Serial.println(" Volts");
  double Rs=(1+(100000/1000))*100000*(5/Voltage)-100000-10000;
  mySerial.println(Rs/4);
  Serial.print("Sensor resistance : ");
  Serial.print(Rs/1000000);
  Serial.println(" Mohms");
  
  // __________ Encodeur rotatoire _________________________
  Serial.print("Position:");
  Serial.println(encoder0Pos, DEC);
  if (Encoder_memo!=encoder0Pos) {
      // surligne la ligne en dessous
     line = OLEDunderline(line);
  }
  Encoder_memo = encoder0Pos;
  Serial.print("switch0: ");
  Serial.println(switch0);
  if (Switch_memo!=switch0) { // entrer dans un menu
    if (((line-1)%3)==0) {
      MenuAuthors();
      Serial.println("---------Switch a marché");
    }
    else {
      if (((line-1)%2)==1){
        if (encoder0Pos>65500){ // if the value is too high OLED screen can not display the number
          MenuEncoder(encoder0Pos-65500);         
        }
        else {
          MenuEncoder(encoder0Pos);
        }
        Serial.println("---------Switch a marché");
      }
      if (((line-1)%2)==0){
        MenuResistance(Rs/(double)1000);
        Serial.println("---------Switch a marché");
      }
    }
  }
  Switch_memo=switch0;
}

// _________ Interrupts: Encodeur rotatoire ___________
void doEncoder(){
  if (digitalRead(encoder0PinB)==HIGH){
    encoder0Pos++;
  }else{
    encoder0Pos--;
  }
}

void doSwitch(){
  if (digitalRead(Switch)==HIGH){
    switch0++;
  }
}

// __________ OLED functions _____________
int OLEDunderline(int line) {
  ecranOLED.clearDisplay();
  ecranOLED.setCursor(0, 1);
  ecranOLED.setTextColor(SSD1306_WHITE);
  ecranOLED.println("Menu :");
    if ((line%3)==0) {
     ecranOLED.println("Resistance");
     ecranOLED.println("Encoder");
     ecranOLED.setTextColor(SSD1306_BLACK,SSD1306_WHITE);
     ecranOLED.println("Authors");
    }
    else {
      if ((line%2)==0){
         ecranOLED.setTextColor(SSD1306_BLACK,SSD1306_WHITE);
         ecranOLED.println("Resistance");
         ecranOLED.setTextColor(SSD1306_WHITE);
         ecranOLED.println("Encoder");
         ecranOLED.println("Authors");
      }     
      if ((line%2)==1) {
         ecranOLED.println("Resistance");
         ecranOLED.setTextColor(SSD1306_BLACK,SSD1306_WHITE);
         ecranOLED.println("Encoder");
         ecranOLED.setTextColor(SSD1306_WHITE);
         ecranOLED.println("Authors");
      }
    }
  ecranOLED.display();
  return line+1;
}

void MenuResistance(double res){
  Serial.println(res);
  ecranOLED.clearDisplay();
  ecranOLED.setCursor(0, 1);
  ecranOLED.setTextColor(SSD1306_WHITE);
  ecranOLED.println(" ");
  ecranOLED.println("Resistance");
  ecranOLED.print("R:");
  ecranOLED.print(res);
  ecranOLED.print(" kOhm");
  ecranOLED.display();
  delay(500);
}

void MenuEncoder(int pos) {
  Serial.println(pos);
  ecranOLED.clearDisplay();
  ecranOLED.setCursor(0, 1);
  ecranOLED.setTextColor(SSD1306_WHITE);
  ecranOLED.println(" ");
  ecranOLED.println("Encoder");
  ecranOLED.println("position:");
  ecranOLED.print(pos);
  ecranOLED.display();
}

void MenuAuthors() {
  ecranOLED.clearDisplay();
  ecranOLED.setCursor(0, 1);
  ecranOLED.setTextColor(SSD1306_WHITE);
  ecranOLED.println("Louise ");
  ecranOLED.println(" Coussen");
  ecranOLED.println("Sarah");
  ecranOLED.println(" Barnova");
  ecranOLED.display();
}

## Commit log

2022-04-15 Create KY-040 Rotary Encoder.STEP
    [KY-040 Rotary Encoder.STEP]
2022-04-16 Electronic_circuit_design.pdf
    This document comments electronic design. Main focus is on filters and cut-off frequencies
